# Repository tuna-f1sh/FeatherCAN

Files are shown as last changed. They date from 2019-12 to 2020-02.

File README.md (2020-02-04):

# Board Details

* MCP2515 SPI CAN Controller: Provides the missing CAN peripheral for the Feather SAMD21. Compatible with the [MCP2515 Arduino Library](https://github.com/autowp/arduino-mcp2515) initialising with `CS #6` and `INT #5`. The track to `#5` can be cut if the user does not require interrupts and wishes to use the pin for something else. 16 MHz crystal used for high-data rate capture.
* SN65HVD230 CAN Transceiver: Front-end for the differential CAN signals; -2/7 V common mode range on bus, +/- 25 kV ESD protection and upto 1 Mbps datarate. Slope can be controlled with the R<sub>s</sub> resistor `R2`, by default it is configured in 'high-speed' mode (RX and TX active). A 120R termination resistor is on-board but not connected by default (a solder link is provided to being in circuit). UPDATE: I've now routed the transeiver RX/TX to pins `#9` and `#10` so that the _STM32 Feather_ can use the on-board CAN peripheral rather than MCP2515.
* RX/TX LEDS: I've tied pull-up LEDs on the transmission lines between the MCP2515 and MCP2551 to provide indication of activity. They should not degrade the signal as they are low current (2 mA) but can be removed if edges are lost at high-speed.
* MCP1703T-5002E: 5 V LDO provides power to the Feather via __VUSB__ given a source of 5-16 V. The board __3V3__ is then powered by the Feather's on-board 3V3 regulator. __NOTE__ VIN should not be supplied with __VUSB__ to avoid back-powering the USB port.
* DS3231: Commonly used high-accuracy RTC module with on-board CR1220 back-up battery. Compatible with the [DS3231 Arduino Library](https://github.com/JChristensen/DS3232RTC).
* Hand-drawn silk art! Something I did on the train, inspired by feather's and bikes! CAN is synonymous with the automotive industry so I wanted to put a bike spin on things...

## Potential Improvements for Mass Assembly

* Make 0603 passives 0402.
* Use same CR1220 holder as Adafruit RTC Wing.

# Availability

I have some bare boards in fabrication at the moment, which I plan to hand-assemble for my own use. If there is interest, I will get an assembly run done (unless it wins the competition of course!) after this validation.

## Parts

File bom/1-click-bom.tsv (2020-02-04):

References | Qty | Characteristics | Config | Description | MFN | MPN | Notes | SKU | Vendor
BT1 | 1 |  |  |  | Linx Technologies | BAT-HLD-012-SMT-TR |  | BAT-HLD-012-SMTCT-ND | Digikey
C1, C2 | 2 | X5R 20V
C3, C4 | 2 | NPO 6V
C5, C6 | 2 | X7R 6V
D1 | 1 | Orange |  | Orange 605nm LED Indication - Discrete 1.8V 2mA 0603 (1608 Metric) | Kingbright | APT1608LSECK/J4-PRV |  | 754-1931-1-ND | Digikey
D2 | 1 | Orange |  | Orange 605nm LED Indication - Discrete 1.8V 2mA 0603 (1608 Metric) | Kingbright | APT1608LSECK/J4-PRV |  | 754-1931-1-ND | Digikey
D3 | 1 | Green |  | Green 525nm LED Indication - Discrete 2.65V 2mA 0603 (1608 Metric) | Kingbright | APT1608LZGCK |  | 754-1934-1-ND | Digikey
D4 | 1 | 40V 200mA |  | Diode Schottky 40V 200mA (DC) Surface Mount 0603 (1608 Metric) | AVX Corporation | SD0603S040S0R2 | Don't allow back powering bus and reverse polarity protect | 478-7798-1-ND | Digikey
J1 | 1 |  | nofit
J2 | 1 |  | nofit
J3 | 1 |  | nofit
J4 | 1 |  |  |  | Molex | 53261-0471 |  | WM7622CT-ND | Digikey
JP1 | 1 |  | nofit |  |  |  | Link to bring termination resistor in circuit
JP2 | 1 |  | nofit |  |  |  | Cut to remove INT connection to Feather
JP3, JP4, JP5 | 3 |  | nofit |  |  |  | Cut to remove INT connection to Feather
R1 | 1 | 1% |  | Rterm
R2 | 1 |  |  |  |  |  | Rext controls mode and slew rate. GND = high-speed, 10 μA < -IRS < 200 μA slope control
R3, R4, R5, R8 | 4
R6, R7 | 2
U1 | 1 |  |  |  | Maxim | DS3231MZ+ |  | DS3231MZ+-ND | Digikey
U2 | 1 |  |  |  | Microchip Technology | MCP2515T-I/ST |  | MCP2515T-I/STCT-ND | Digikey
U3 | 1 |  |  | IC TRANSCEIVER HALF 1/1 8SOIC | Texas Instruments | SN65HVD230DR | MCP2551 drop in replacement | 296-11654-1-ND | Digikey
U4 | 1 |  |  | 5 V LDO | Microchip Technology | MCP1703T-5002E/CB |  | MCP1703T-5002E/CBCT-ND | Digikey
Y1 | 1 |  |  | 9pF | Epson | TSX-3225 16.0000MF18X-AC0 |  | SER4070CT-ND | Digikey

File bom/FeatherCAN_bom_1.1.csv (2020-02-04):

Component | Description | Part | References | Value | Footprint | Quantity Per PCB | Datasheet | SKU | Vendor | MPN | MFN | Characteristics | Notes | Config
1 | Single-cell battery | Battery_Cell | BT1 | CR1220 | BatteryHolder_LINX_BAT-HLD-012-SMT | 1 | ~ | BAT-HLD-012-SMTCT-ND | Digikey | BAT-HLD-012-SMT-TR | Linx Technologies
2 | Unpolarized capacitor | C | C5 C6 | 100nF | C_0603_1608Metric | 2 | ~ |  |  |  |  | X7R 6V
3 | Unpolarized capacitor | C | C1 C2 | 1uF | C_0603_1608Metric | 2 | ~ |  |  |  |  | X5R 20V
4 | Unpolarized capacitor | C | C3 C4 | 8pF | C_0603_1608Metric | 2 | ~ |  |  |  |  | NPO 6V
5 | Diode, small symbol | D_Small | D4 | 40V 200mA | D_0603_1608Metric | 1 | ~ | 478-7798-1-ND | Digikey | SD0603S040S0R2 | AVX Corporation | 40V 200mA | Don't allow back powering bus and reverse polarity protect
6 | Light emitting diode | LED | D3 | PWR | LED_0603_1608Metric | 1 | http://www.kingbrightusa.com/images/catalog/SPEC/APT1608LZGCK.pdf | 754-1934-1-ND | Digikey | APT1608LZGCK | Kingbright | Green
7 | Light emitting diode | LED | D2 | RXD | LED_0603_1608Metric | 1 | http://www.kingbrightusa.com/images/catalog/SPEC/APT1608LSECK-J4-PRV.pdf | 754-1931-1-ND | Digikey | APT1608LSECK/J4-PRV | Kingbright | Orange
8 | Light emitting diode | LED | D1 | TXD | LED_0603_1608Metric | 1 | http://www.kingbrightusa.com/images/catalog/SPEC/APT1608LSECK-J4-PRV.pdf | 754-1931-1-ND | Digikey | APT1608LSECK/J4-PRV | Kingbright | Orange
9 | Generic connector, single row, 01x04, script generated (kicad-library-utils/schlib/autogen/connector/) | Conn_01x04_Male | J4 | PicoBlade | Molex_PicoBlade_53261-0471_1x04-1MP_P1.25mm_Horizontal | 1 | ~ | WM7622CT-ND | Digikey | 53261-0471 | Molex
10 | Resistor, small symbol | R_Small | R2 | 0R | R_0603_1608Metric | 1 |  |  |  |  |  |  | Rext controls mode and slew rate. GND = high-speed, 10 μA < -IRS < 200 μA slope control
11 | Resistor, small symbol | R_Small | R1 | 120R | R_0603_1608Metric | 1 |  |  |  |  |  | 1%
12 | Resistor, small symbol | R_Small | R3 R4 R5 R8 | 1k | R_0603_1608Metric | 4
13 | Resistor, small symbol | R_Small | R6 R7 | 4k7 | R_0603_1608Metric | 2
14 | 250mA Low Quiscent Current LDO, 5.0V output, SOT-23 | MCP1700-5002E_SOT23 | U4 | 5V | SOT-23 | 1 | http://www.microchip.com/mymicrochip/filehandler.aspx?ddocname=en530937 | MCP1703T-5002E/CBCT-ND | Digikey | MCP1703T-5002E/CB | Microchip Technology
15 | ±5ppm, I2C Real-Time Clock SOIC-8 | DS3231MZ | U1 | DS3231MZ | SOIC-8_3.9x4.9mm_P1.27mm | 1 | http://datasheets.maximintegrated.com/en/ds/DS3231M.pdf | DS3231MZ+-ND | Digikey | DS3231MZ+ | Maxim
16 | Stand-Alone CAN Controller with SPI Interface, TSSOP-20 | MCP2515-xST | U2 | MCP2515-xST | TSSOP-20_4.4x6.5mm_P0.65mm | 1 | http://ww1.microchip.com/downloads/en/DeviceDoc/MCP2515-Stand-Alone-CAN-Controller-with-SPI-20001801J.pdf | MCP2515T-I/STCT-ND | Digikey | MCP2515T-I/ST | Microchip Technology
17 | CAN Bus Transceivers, 3.3V, 1Mbps, Low-Power capabilities, SOIC | SN65HVD230 | U3 | SN65HVD230 | SOIC-8_3.9x4.9mm_P1.27mm | 1 | http://www.ti.com/lit/ds/symlink/sn65hvd230.pdf | 296-11654-1-ND | Digikey | SN65HVD230DR | Texas Instruments |  | MCP2551 drop in replacement
18 | Four pin crystal, GND on pins 2 and 4, small symbol | Crystal_GND24_Small | Y1 | 16MHz | Crystal_SMD_3225-4Pin_3.2x2.5mm | 1 | https://support.epson.biz/td/api/doc_check.php?dl=brief_TSX-3225&lang=en | SER4070CT-ND | Digikey | TSX-3225 16.0000MF18X-AC0 | Epson
Component Groups: | 23
Component Count: | 32
Fitted Components: | 25
Number of PCBs: | 1
Total components: | 25
Schematic Version: | 1.1
Schematic Date: | 2020-01-22
PCB Variant: | [u'default']
BoM Date: | 2020 February 04, Tuesday 14:12:21
Schematic Source: | /Users/john/Dropbox/specialized/FeatherCAN/FeatherCAN.sch
KiCad Version: | Eeschema (5.1.5-0-10_14)

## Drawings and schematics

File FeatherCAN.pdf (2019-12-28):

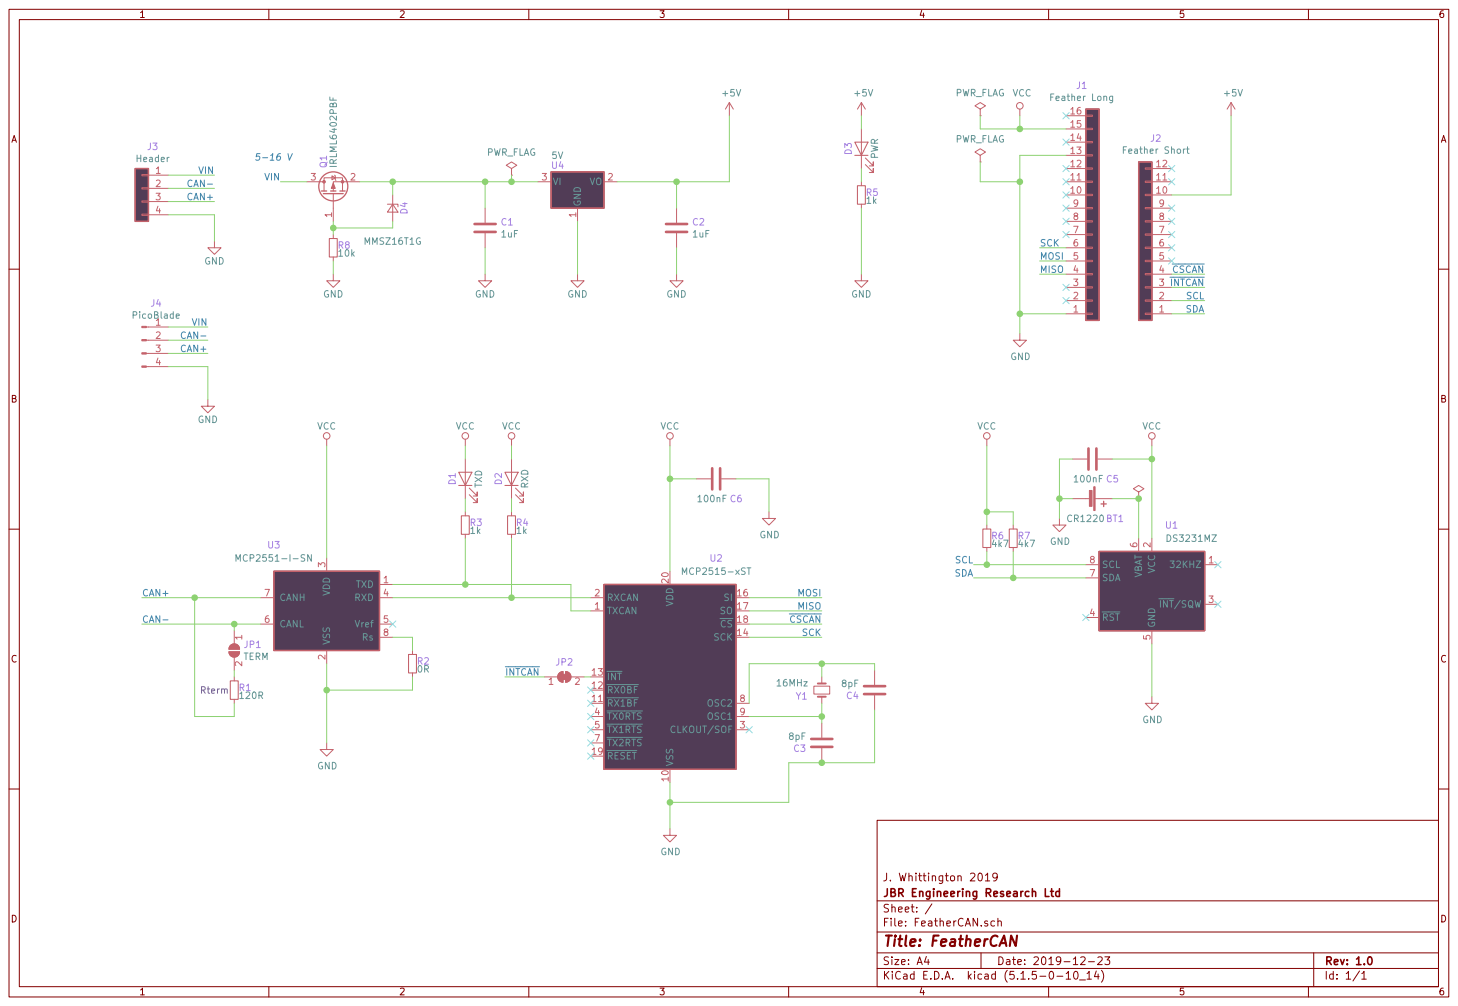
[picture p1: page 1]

3 RXD 4 Vref 5 CANL 6 CANH 7 Rs 8 U3 MCP2551-I-SN 32KHZ 1 VCC

J. Whittington 2019
File: FeatherCAN.sch Sheet: / JBR Engineering Research Ltd

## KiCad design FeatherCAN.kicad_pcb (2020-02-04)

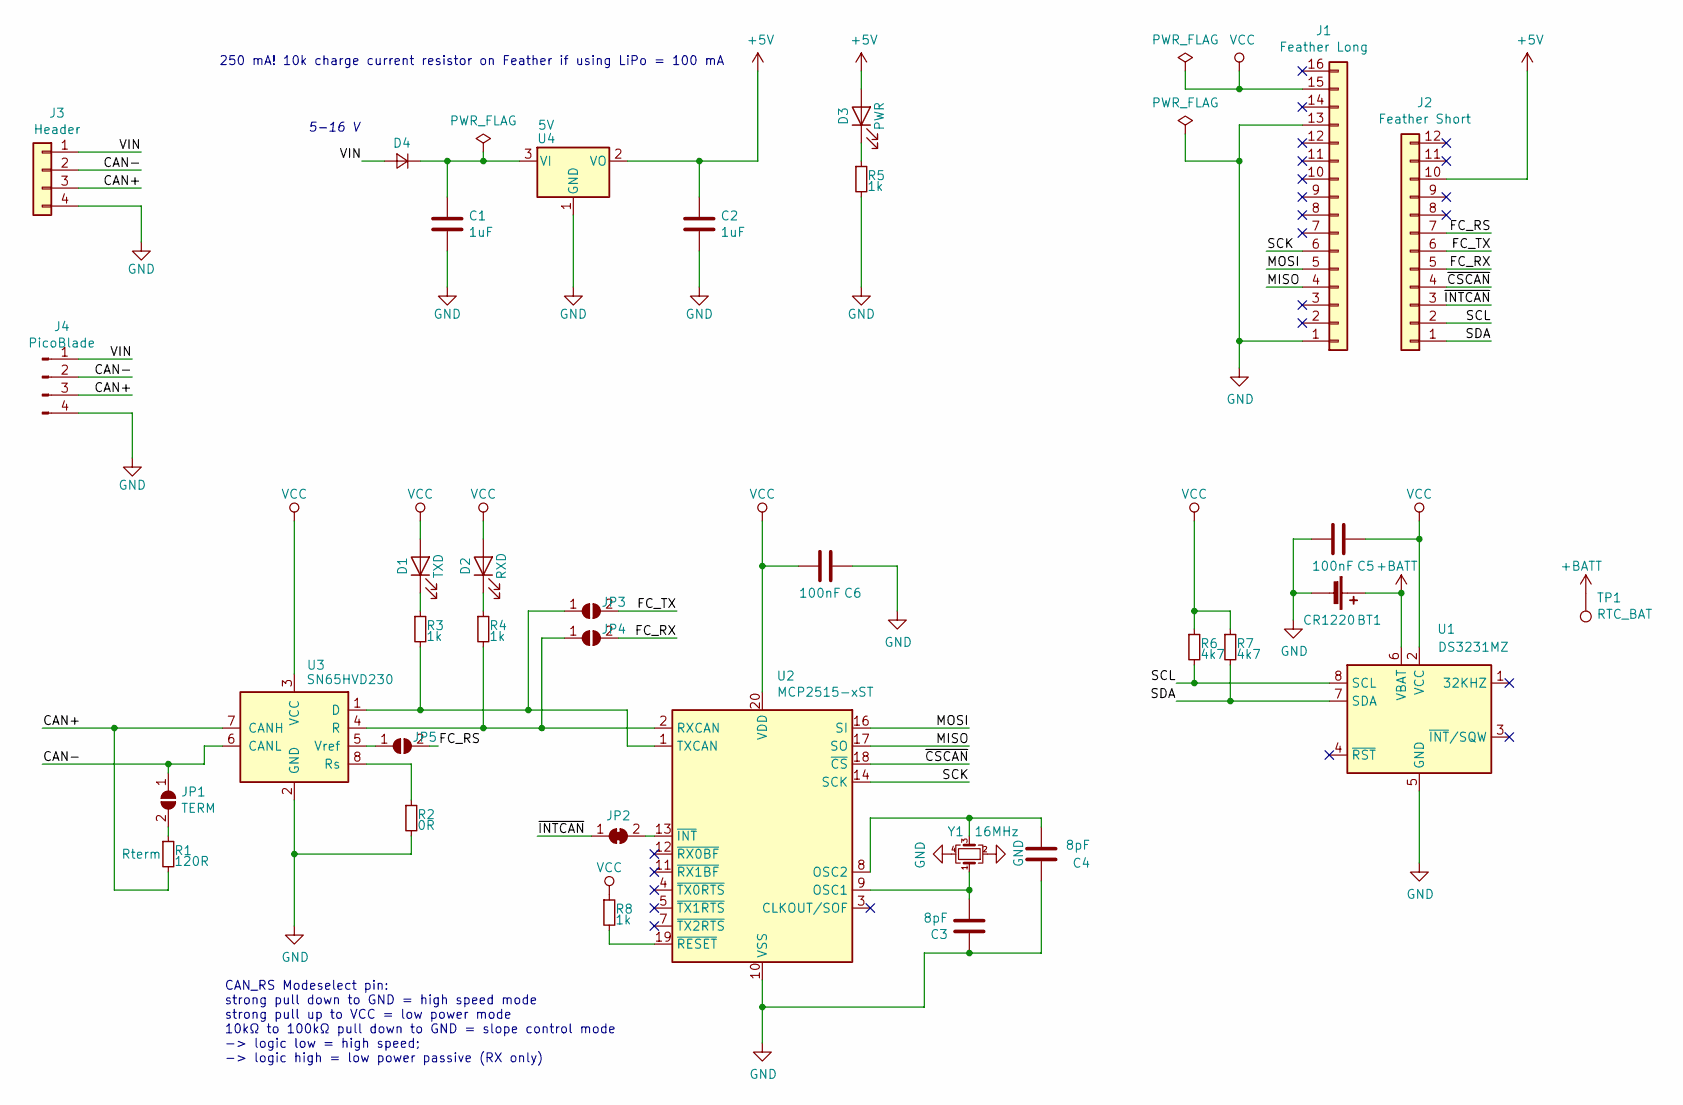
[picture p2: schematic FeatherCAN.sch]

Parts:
BT1: CR1220; BatteryHolder_LINX_BAT-HLD-012-SMT; MPN BAT-HLD-012-SMT-TR
C1, C2: 1uF; C_0603_1608Metric
C3, C4: 8pF; C_0603_1608Metric
C5, C6: 100nF; C_0603_1608Metric
D1: TXD; LED_0603_1608Metric; MPN APT1608LSECK/J4-PRV
D2: RXD; LED_0603_1608Metric; MPN APT1608LSECK/J4-PRV
D3: PWR; LED_0603_1608Metric; MPN APT1608LZGCK
D4: 40V 200mA; D_0603_1608Metric; MPN SD0603S040S0R2
J1: Feather Long; PinHeader_1x16_P2.54mm_Vertical
J2: Feather Short; PinHeader_1x12_P2.54mm_Vertical
J3: Header; PinHeader_1x04_P2.54mm_Vertical
J4: PicoBlade; Molex_PicoBlade_53261-0471_1x04-1MP_P1.25mm_Horizontal; MPN 53261-0471
JP1: TERM; SolderJumper-2_P1.3mm_Open_RoundedPad1.0x1.5mm
JP2: INT; SolderJumper-2_P1.3mm_Bridged_RoundedPad1.0x1.5mm
JP3, JP4, JP5: INT; SolderJumper-2_P1.3mm_Open_RoundedPad1.0x1.5mm
R1: 120R; R_0603_1608Metric
R2: 0R; R_0603_1608Metric
R3, R4, R5, R8: 1k; R_0603_1608Metric
R6, R7: 4k7; R_0603_1608Metric
TP1: RTC_BAT; TestPoint_Pad_D2.5mm
U1: DS3231MZ; SOIC-8_3.9x4.9mm_P1.27mm; MPN DS3231MZ+
U2: MCP2515-xST; TSSOP-20_4.4x6.5mm_P0.65mm; MPN MCP2515T-I/ST
U3: SN65HVD230; SOIC-8_3.9x4.9mm_P1.27mm; MPN SN65HVD230DR
U4: 5V; SOT-23; MPN MCP1703T-5002E/CB
Y1: 16MHz; Crystal_SMD_3225-4Pin_3.2x2.5mm; MPN TSX-3225 16.0000MF18X-AC0

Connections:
+5V: C2.1, D3.2 (A), J2.10, U4.2 (VO)
+BATT: BT1.1 (+), TP1.1, U1.6 (VBAT)
/CAN+: J3.3, J4.3, R1.2, U3.7 (CANH)
/CAN-: J3.2, J4.2, JP1.1 (A), U3.6 (CANL)
/FC_RS: J2.7, JP5.2 (B)
/FC_RX: J2.5, JP4.2 (B)
/FC_TX: J2.6, JP3.2 (B)
/MISO: J1.4, U2.17 (SO)
/MOSI: J1.5, U2.16 (SI)
/SCK: J1.6, U2.14 (SCK)
/SCL: J2.2, R6.2, U1.8 (SCL)
/SDA: J2.1, R7.2, U1.7 (SDA)
/VIN: D4.2 (A), J3.1, J4.1
/~CSCAN: J2.4, U2.18 (~CS)
/~INTCAN: J2.3, JP2.1 (A)
GND: BT1.2 (-), C1.2, C2.2, C3.1, C4.1, C5.2, C6.1, J1.1, J1.13, J3.4, J4.4, R2.2, R5.2, U1.5 (GND), U2.10 (VSS), U3.2 (GND), U4.1 (GND), Y1.2, Y1.4
unnamed: C1.1, D4.1 (K), U4.3 (VI)
unnamed: C3.2, U2.9 (OSC1), Y1.1
unnamed: C4.2, U2.8 (OSC2), Y1.3
unnamed: D1.1 (K), R3.1
unnamed: D2.1 (K), R4.1
unnamed: D3.1 (K), R5.1
unnamed: JP1.2 (B), R1.1
unnamed: JP2.2 (B), U2.13 (~INT)
unnamed: JP3.1 (A), R3.2, U2.1 (TXCAN), U3.1 (D)
unnamed: JP4.1 (A), R4.2, U2.2 (RXCAN), U3.4 (R)
unnamed: JP5.1 (A), U3.5 (Vref)
unnamed: R2.1, U3.8 (Rs)
unnamed: R8.2, U2.19 (~RESET)
VCC: C5.1, C6.2, D1.2 (A), D2.2 (A), J1.15, R6.1, R7.1, R8.1, U1.2 (VCC), U2.20 (VDD), U3.3 (VCC)

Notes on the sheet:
5-16 V
250 mA! 10k charge current resistor on Feather if using LiPo = 100 mA
CAN_RS Modeselect pin: strong pull down to GND = high speed mode strong pull up to VCC = low power mode 10kΩ to 100kΩ pull down to GND = slope control mode -> logic low = high speed; -> logic high = low power passive (RX only)

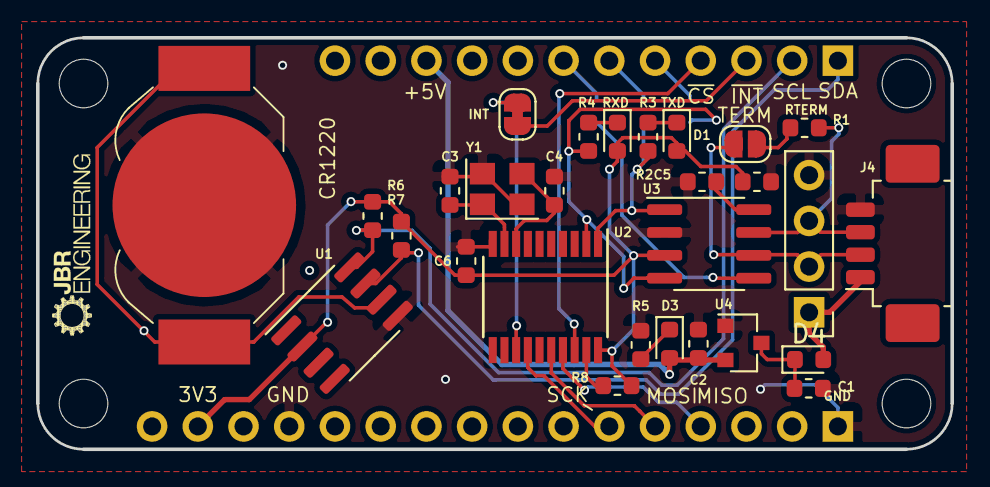
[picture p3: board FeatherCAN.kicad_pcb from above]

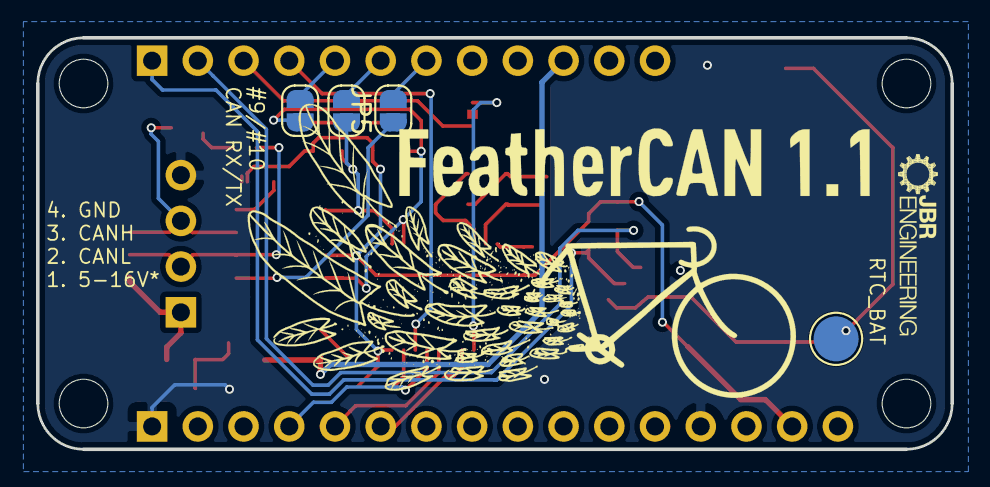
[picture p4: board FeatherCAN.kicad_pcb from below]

Board: 2 copper layers, 50.8 x 22.9 mm, 34 parts (6 on the bottom side), 30 nets.

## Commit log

2019-12-23 initial schematic capture and layout complete
    [FeatherCAN.kicad_pcb, FeatherCAN.sch]
2019-12-23 first version sent for production review
    [FeatherCAN.kicad_pcb, FeatherCAN.sch]
2019-12-28 add README and silk logo
    [FeatherCAN.kicad_pcb]
2019-12-28 reverse polority protect and clamp VIN
    [FeatherCAN.sch]
2020-01-06 add part numbers
    [FeatherCAN.sch]
2020-01-15 pull-up on MCP reset and fix 4-pad crystal pins
    [FeatherCAN.kicad_pcb, FeatherCAN.sch]
2020-01-22 add CAN transeiver lines for STM32 Feather peripheral
    STM32 Feather has CAN RX/TX on #9 and #10. Can be cut if user wants to
    use pins on other Feather.
    [FeatherCAN.kicad_pcb, FeatherCAN.sch]
2020-01-22 MCP2515 Vdd is +5 V
    [FeatherCAN.kicad_pcb, FeatherCAN.sch]
2020-02-04 gerbers and kitspcae
    [FeatherCAN-B_Adhes.gbr, FeatherCAN-B_Cu.gbr, FeatherCAN-B_Fab.gbr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]
2020-02-04 correct MFP/MPN and add kitspace tsv
    [1-click-bom.tsv, FeatherCAN.sch, FeatherCAN_bom_1.1.csv]
2020-02-04 MCP2551 swap to SN65 for Vcc logic
    [1-click-bom.tsv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]
